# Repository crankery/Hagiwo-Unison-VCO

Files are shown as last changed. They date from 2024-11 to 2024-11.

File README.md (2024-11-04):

# Hagiwo Unison VCO

> [!NOTE]
> This is a work in progress, I'm sure I made a mistake somewhere I'll post an update when I receive the first batch of boards. 

If you don't know Hagiwo, check out their [YouTube channel](https://www.youtube.com/@HAGIWO). He puts out new DIY Eurorack module designs all the time.

This is (what is currently) has latest module, the [Unison VCO](https://note.com/solder_state/n/na0ae5754fa9c). All I've done is switch to SMT devices to try to fit it all on a single 6hp PCB. All credit for the circuit design go to Hagiwo.

The PCB is 100x30mm so it should be pretty darned cheap to order from one of the fabs over in China. Higawo used a [Seeed Studio XIAO RA4M1](https://wiki.seeedstudio.com/getting_started_xiao_ra4m1/) microcontroller module on this one, which are about $5 ordered from Seeed. They're really quite neat.

I added a tiny OLED display module to show the currently selected waveform. The display module is available from all the usual places with with search terms like "0.42" 0.42 Inch White OLED Display LCD Module 72X40 Serial Screen White Color I2C IIC/SPI Interface SSD1306". I'm sure there's an original manufacturer of these things but I can't figure it out. The 4 pin I2C SSD1306 version that looks like this:

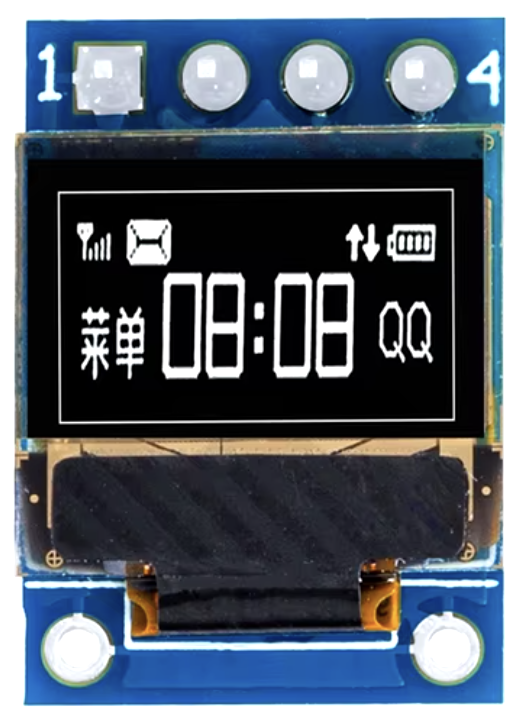
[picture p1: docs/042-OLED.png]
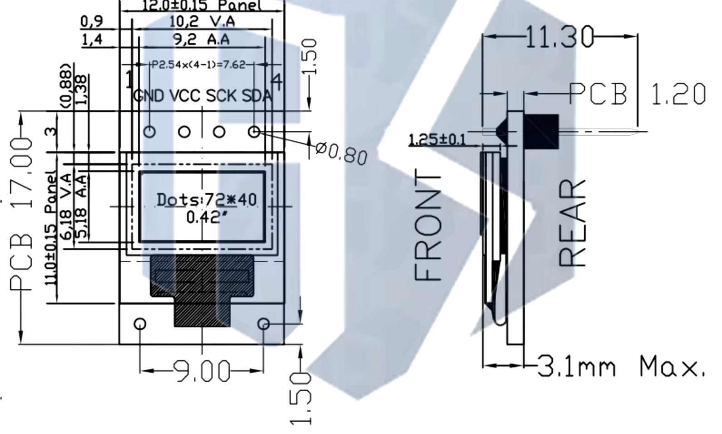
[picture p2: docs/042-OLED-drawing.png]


TODO: make incredibly insightful comments about stuff here

## Main Board

Here's some renderings of this thing. I'll take pictures of it when I actually build it.

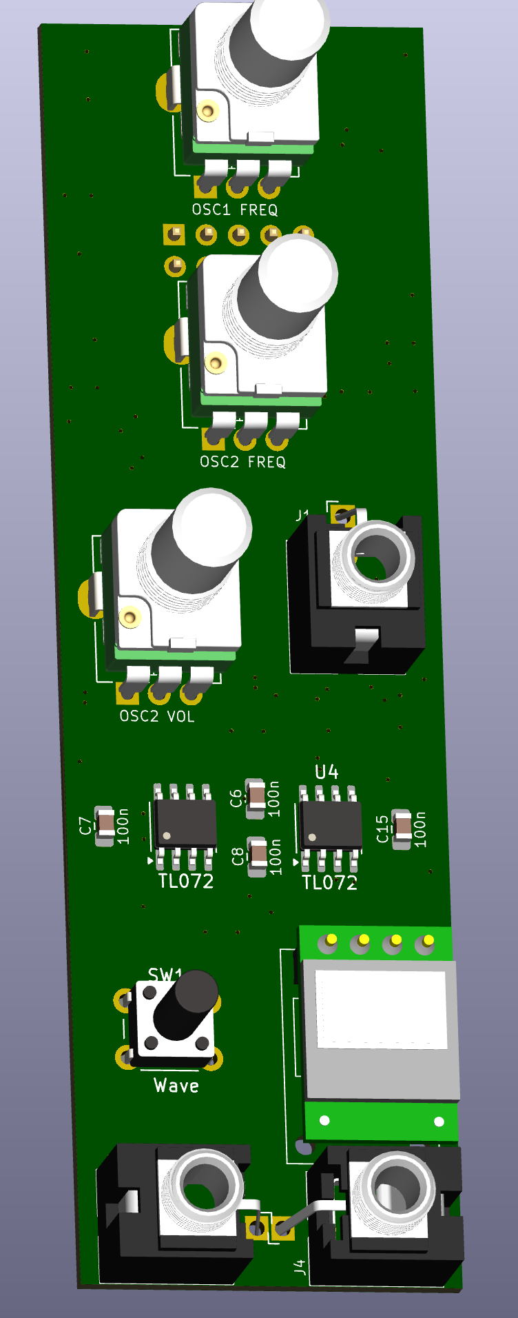
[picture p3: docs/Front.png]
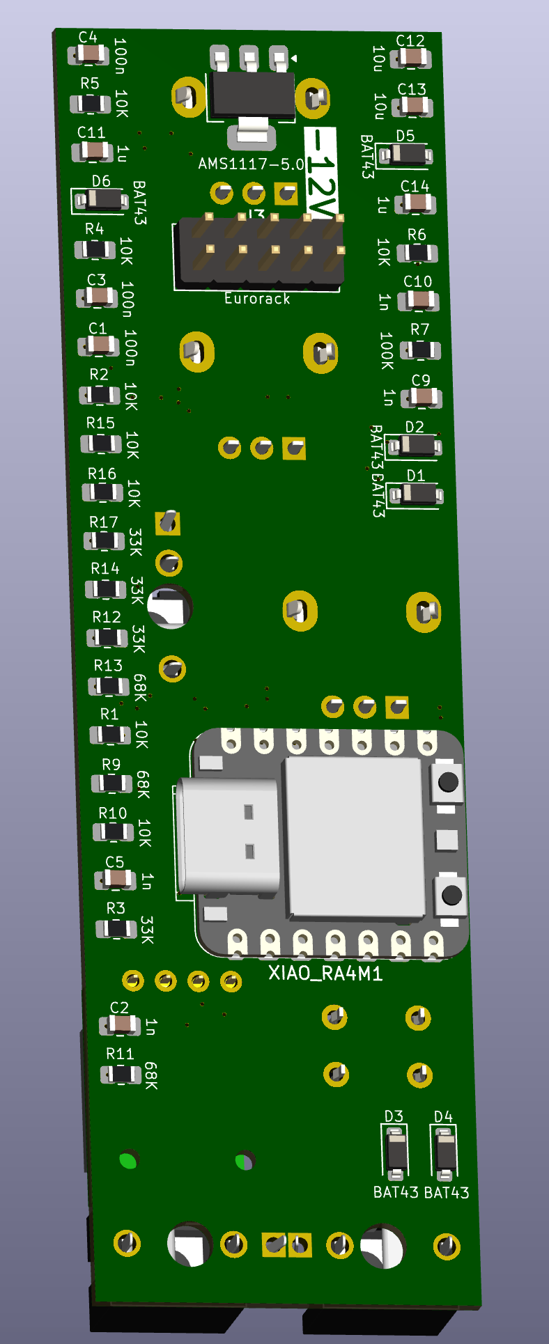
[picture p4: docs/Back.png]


## Front Panel

I created a Eurorack 6hp front panel for this in KiCad. Which is weird but hey. I don't want to pay for aluminum panels.

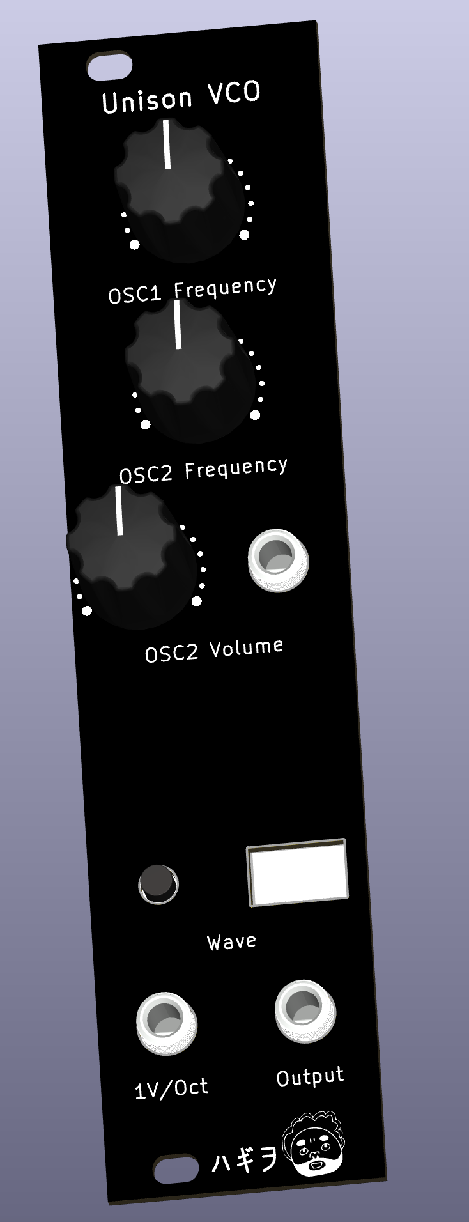
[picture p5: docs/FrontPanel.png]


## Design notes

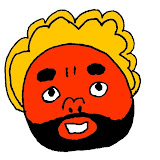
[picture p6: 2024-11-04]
FP/FP.jpg

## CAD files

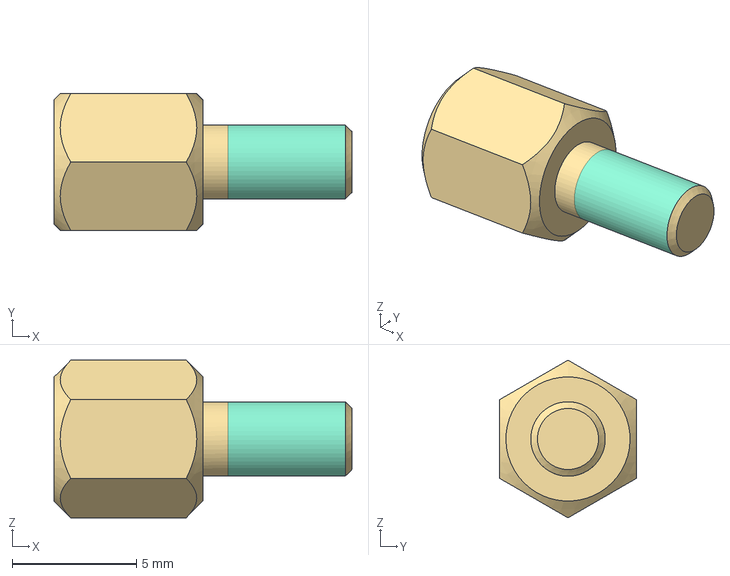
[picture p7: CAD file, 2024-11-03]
3dshapes/Abstandhalter M3 IG-AG 6mm+6mm - Messing.stp
12.0 x 5.50 x 6.35 mm

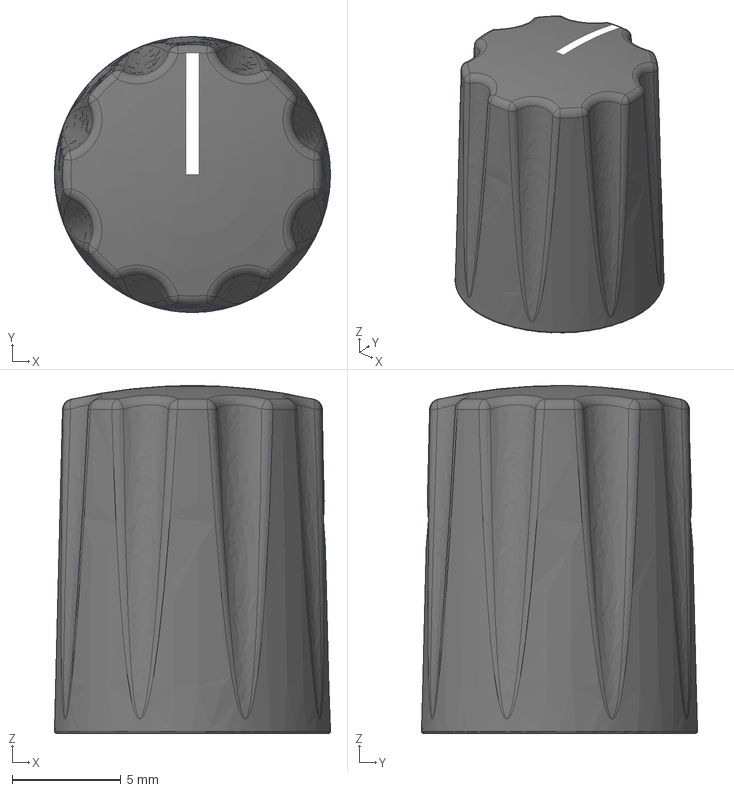
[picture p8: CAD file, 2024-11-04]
FP/3d/1900h-bk-T-D.stp
12.7 x 12.7 x 16.0 mm

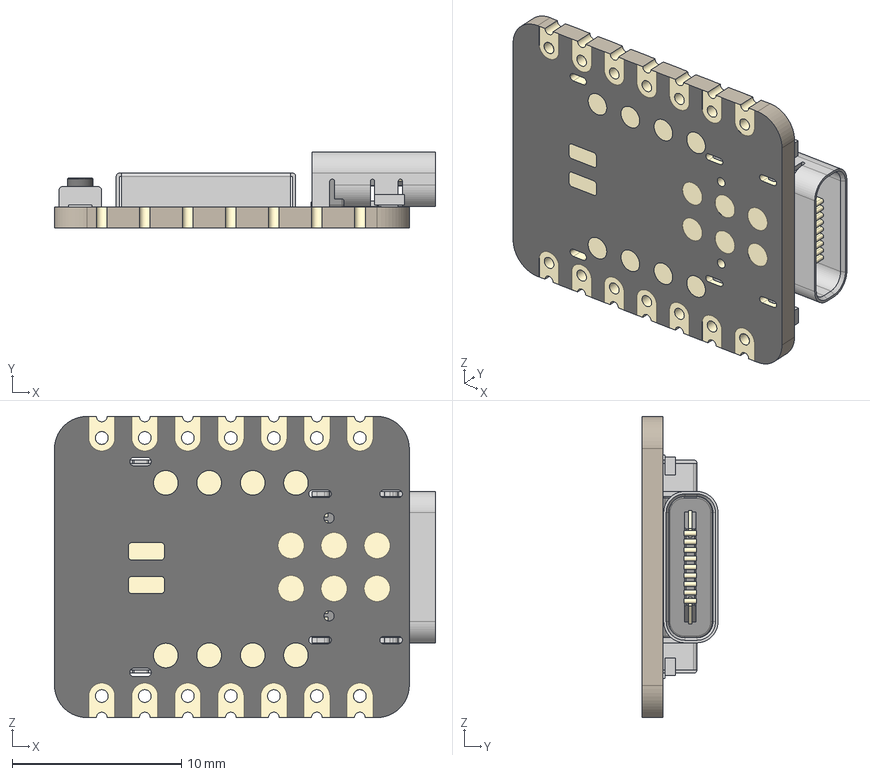
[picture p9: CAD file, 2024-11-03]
3dshapes/Seeed Studio XIAO RA4M1.step
22.5 x 4.49 x 17.8 mm
BOSS-EXTRUDE14_8_
BOSS-EXTRUDE7_4_
BOSS-EXTRUDE7_3_
BOSS-EXTRUDE14_4_
BOSS-EXTRUDE14_2_
BOSS-EXTRUDE14_11_
BOSS-EXTRUDE7_7_
BOSS-EXTRUDE14_9_
BOSS-EXTRUDE14_3_
BOSS-EXTRUDE14_7_
MIRROR2
BOSS-EXTRUDE14_5_
BOSS-EXTRUDE14_12_
BOSS-EXTRUDE7_8_
BOSS-EXTRUDE7_1_
BOSS-EXTRUDE14_10_
BOSS-EXTRUDE7_9_
BOSS-EXTRUDE14_6_
BOSS-EXTRUDE14_1_
BOSS-EXTRUDE7_6_
BOSS-EXTRUDE7_2_
CUT-EXTRUDE5
BOSS-EXTRUDE7_5_
Button (1) x 2
Shield

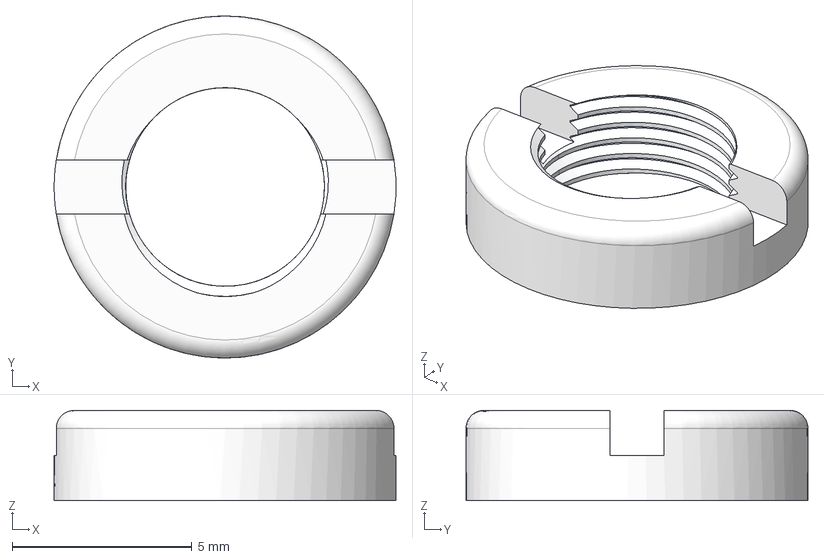
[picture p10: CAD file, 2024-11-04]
FP/3d/Bananut M6 Silver.step
9.50 x 9.51 x 2.51 mm

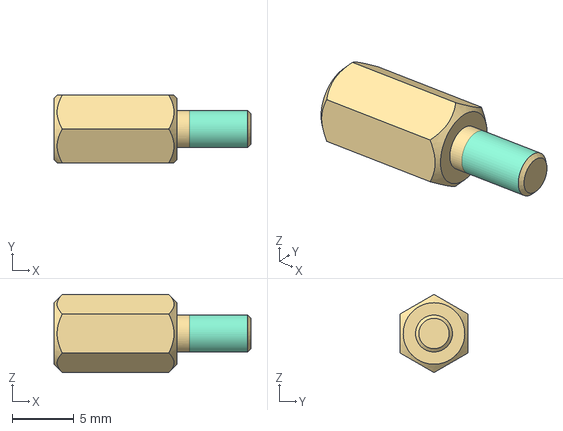
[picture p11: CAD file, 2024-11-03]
3dshapes/Abstandhalter M3 IG-AG 10mm+6mm - Messing.stp
16.0 x 5.50 x 6.35 mm

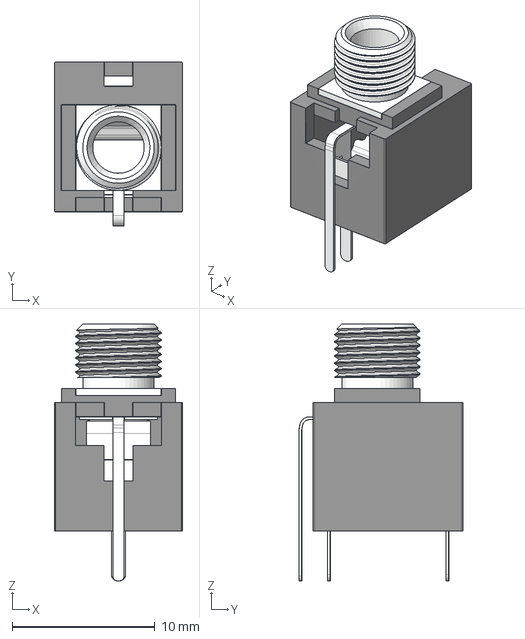
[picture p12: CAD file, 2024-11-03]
FP/3d/PJ398SM.stp
9.00 x 11.5 x 18.0 mm

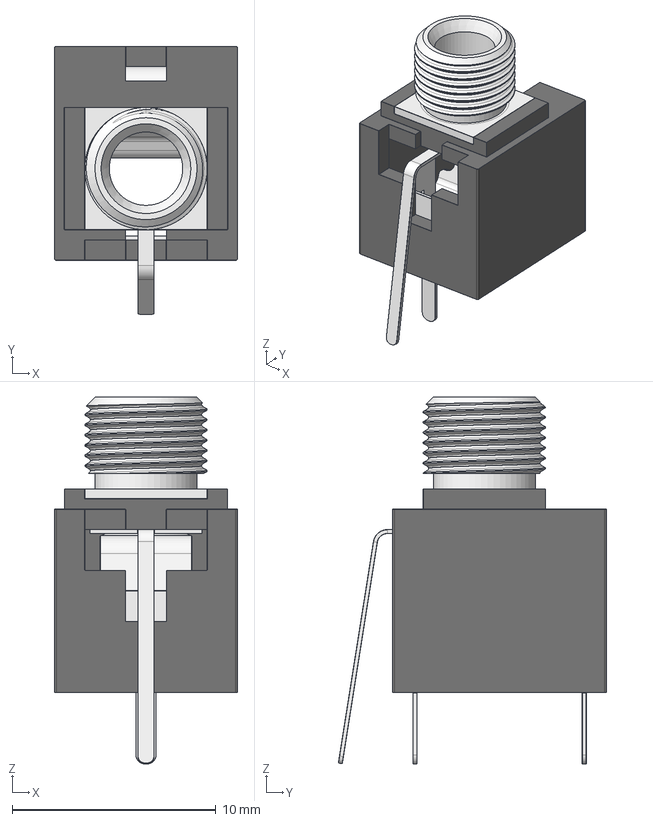
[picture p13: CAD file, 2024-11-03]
3dshapes/WQP-PJ398SM.step
9.00 x 13.2 x 18.0 mm
Pin_3
Pin_2
Pin_1
Socket

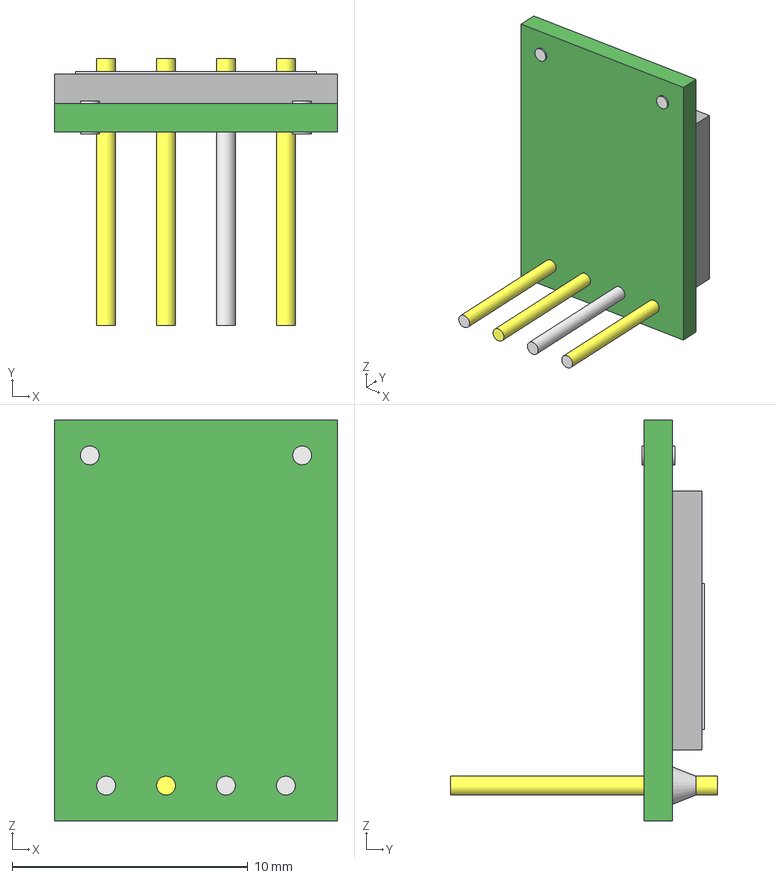
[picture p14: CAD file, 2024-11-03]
3dshapes/display.step
12.0 x 11.3 x 17.0 mm

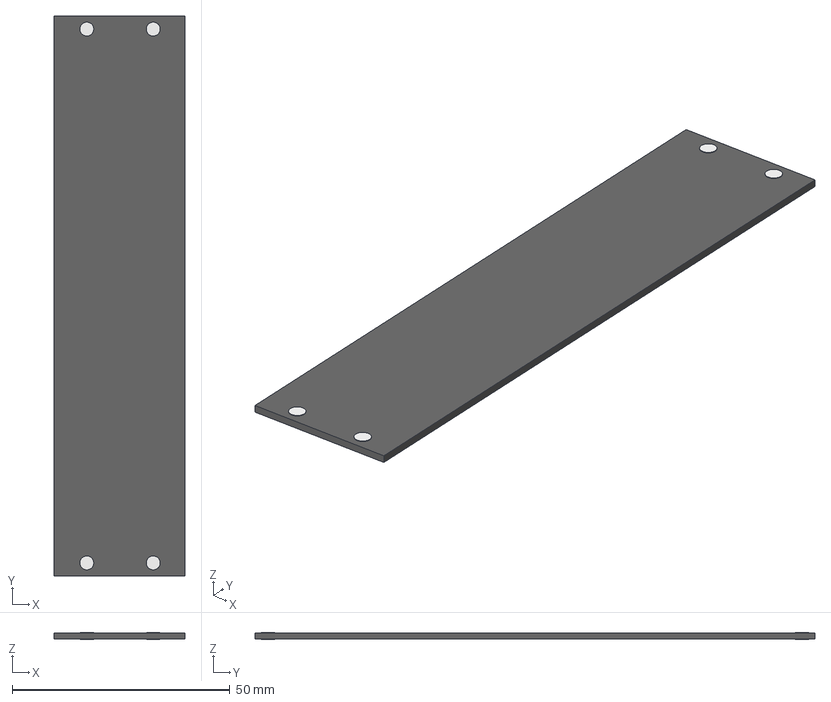
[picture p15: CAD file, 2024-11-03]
3dshapes/fp.step
30.0 x 128.5 x 1.60 mm

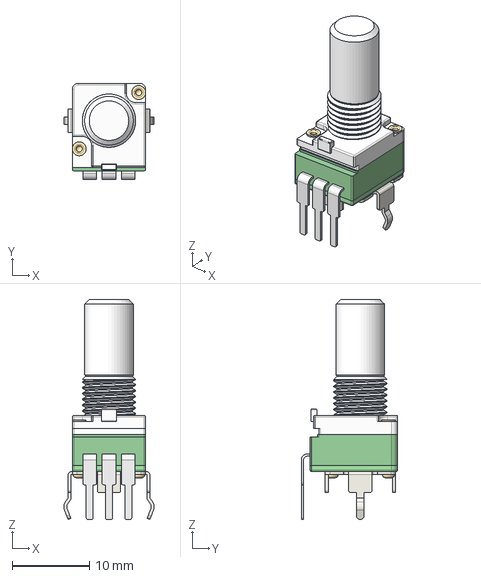
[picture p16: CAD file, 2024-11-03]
3dshapes/RD901F-40-15R1.step
11.7 x 12.5 x 28.5 mm

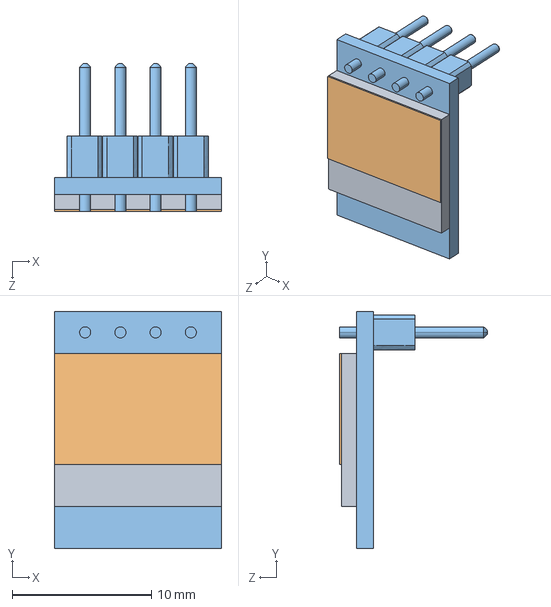
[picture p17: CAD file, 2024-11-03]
3dshapes/042oled.STEP
12.0 x 17.0 x 10.7 mm

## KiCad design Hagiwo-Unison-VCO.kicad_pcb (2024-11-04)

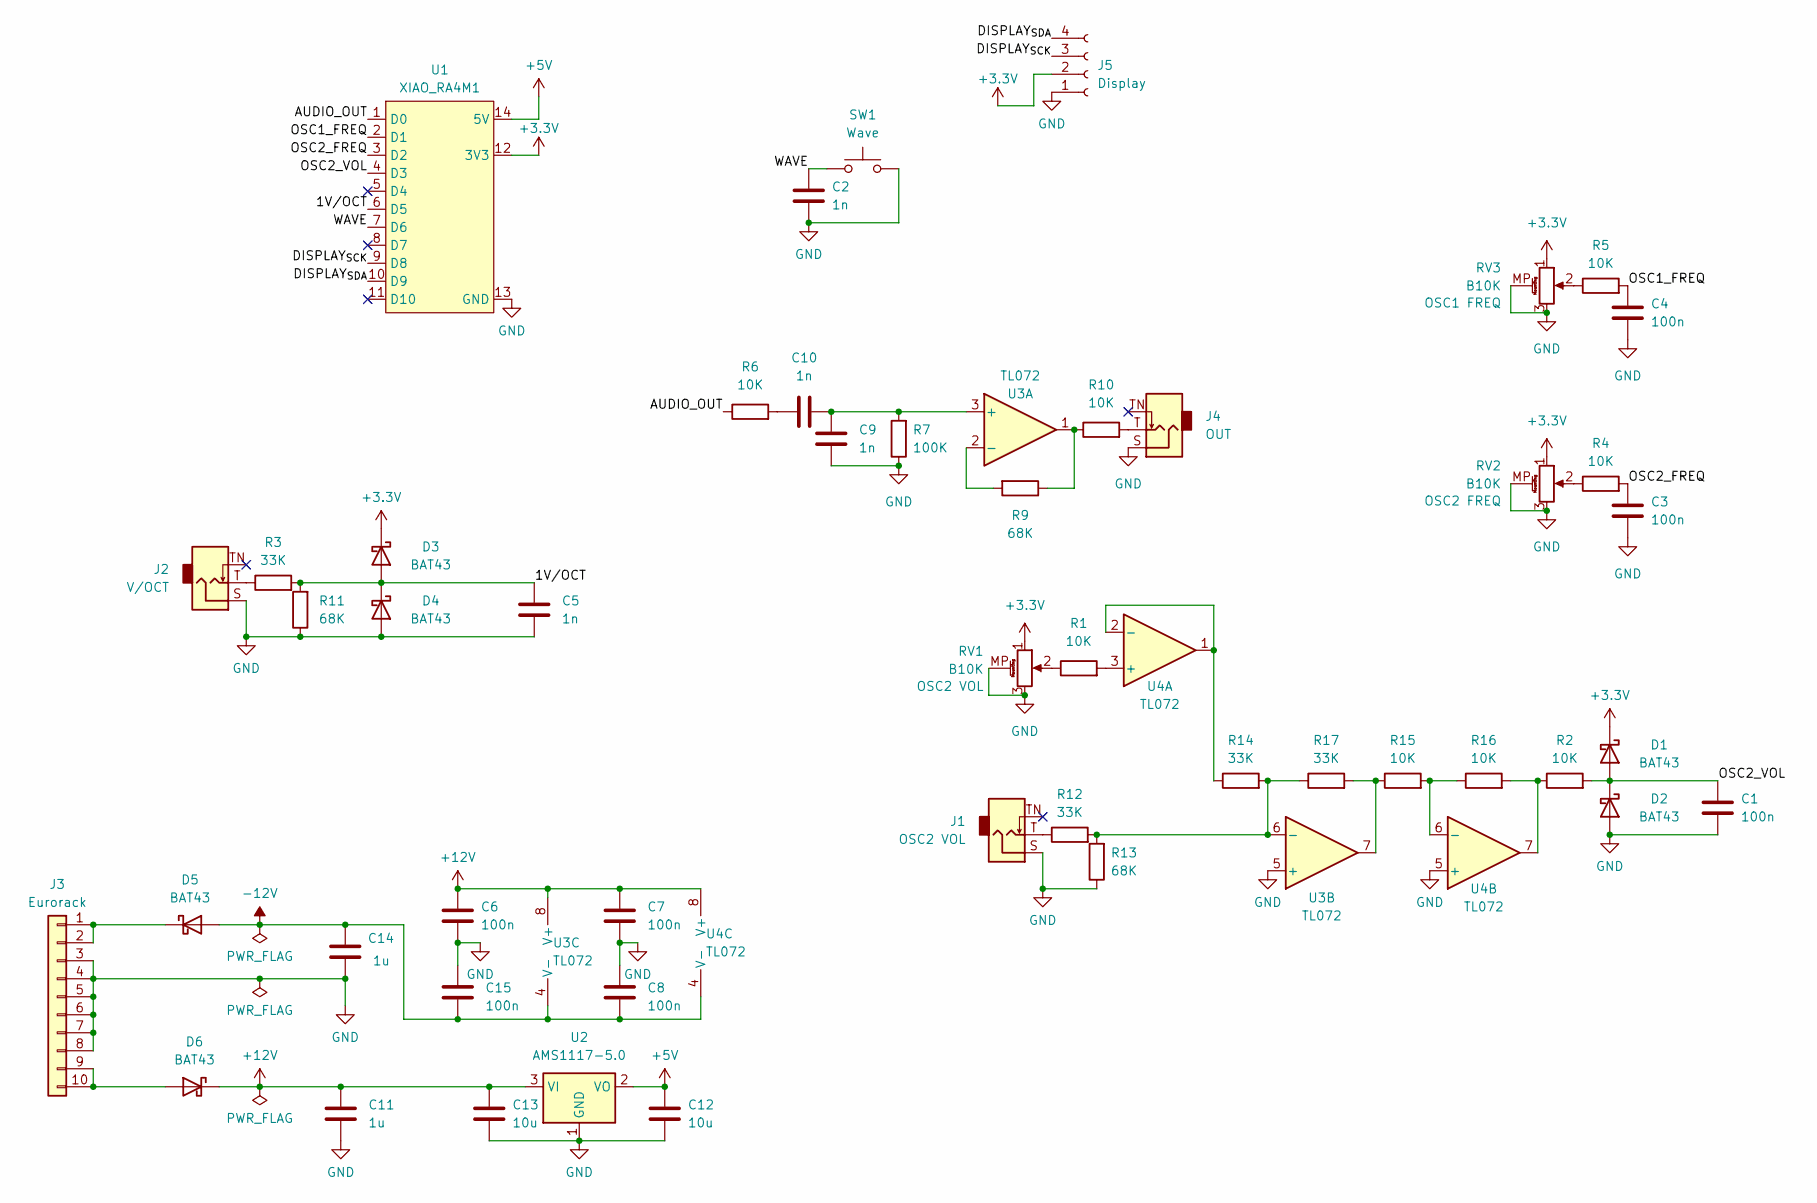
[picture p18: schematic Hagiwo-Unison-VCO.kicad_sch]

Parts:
C1, C3, C4, C6, C7, C8, C15: 100n; C_0805_2012Metric_Pad1.18x1.45mm_HandSolder
C2, C5, C9, C10: 1n; C_0805_2012Metric_Pad1.18x1.45mm_HandSolder
C11, C14: 1u; C_0805_2012Metric_Pad1.18x1.45mm_HandSolder
C12, C13: 10u; C_0805_2012Metric_Pad1.18x1.45mm_HandSolder
D1, D2, D3, D4, D5, D6: BAT43; D_SOD-123
J1: OSC2 VOL; Jack_3.5mm_QingPu_WQP-PJ398SM_Vertical_CircularHoles
J2: V/OCT; Jack_3.5mm_QingPu_WQP-PJ398SM_Vertical_CircularHoles
J3: Eurorack; PinHeader_2x05_P2.54mm_Vertical
J4: OUT; Jack_3.5mm_QingPu_WQP-PJ398SM_Vertical_CircularHoles
J5: Display; 0.42_OLED
R1, R2, R4, R5, R6, R10, R15, R16: 10K; R_0805_2012Metric_Pad1.20x1.40mm_HandSolder
R3, R12, R14, R17: 33K; R_0805_2012Metric_Pad1.20x1.40mm_HandSolder
R7: 100K; R_0805_2012Metric_Pad1.20x1.40mm_HandSolder
R9, R11, R13: 68K; R_0805_2012Metric_Pad1.20x1.40mm_HandSolder
RV1, RV2, RV3: B10K; Potentiometer_Alpha_RD901F-40-00D_Single_Vertical
SW1: Wave; SW_PUSH_6mm_H13mm
U1: XIAO_RA4M1; Seeed XIAO RA4M1 Basic
U2: AMS1117-5.0; SOT-223-3_TabPin2
U3, U4: TL072; SOIC-8_3.9x4.9mm_P1.27mm

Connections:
+3.3V: D1.1 (K), D3.1 (K), J5.2, RV1.1, RV2.1, RV3.1, U1.12 (3V3)
+5V: C12.2, U1.14 (5V), U2.2 (VO)
+12V: C6.2, C7.2, C11.2, C13.2, D6.1 (K), U2.3 (VI), U3.8 (V+), U4.8 (V+)
-12V: C8.1, C14.2, C15.1, D5.2 (A), U3.4 (V-), U4.4 (V-)
/1V/OCT: C5.2, D3.2 (A), D4.1 (K), R3.2, R11.2, U1.6 (D5)
/AUDIO_OUT: R6.1, U1.1 (D0)
/DISPLAY_{SCK}: J5.3, U1.9 (D8)
/DISPLAY_{SDA}: J5.4, U1.10 (D9)
/OSC1_FREQ: C4.2, R5.2, U1.2 (D1)
/OSC2_FREQ: C3.2, R4.2, U1.3 (D2)
/OSC2_VOL: C1.2, D1.2 (A), D2.1 (K), R2.2, U1.4 (D3)
/WAVE: C2.2, SW1.1, U1.7 (D6)
GND: C1.1, C2.1, C3.1, C4.1, C5.1, C6.1, C7.1, C8.2, C9.1, C11.1, C12.1, C13.1, C14.1, C15.2, D2.2 (A), D4.2 (A), J1.S, J2.S, J3.3, J3.4, J3.5, J3.6, J3.7, J3.8, J4.S, J5.1, R7.1, R11.1, R13.1, RV1.3, RV1.MP (MountPin), RV2.3, RV2.MP (MountPin), RV3.3, RV3.MP (MountPin), SW1.2, U1.13 (GND), U2.1 (GND), U3.5 (+), U4.5 (+)
unnamed: C10.2, R6.2
unnamed: D5.1 (K), J3.1, J3.2
unnamed: D6.2 (A), J3.9, J3.10
unnamed: J1.T, R12.1
unnamed: J2.T, R3.1
unnamed: J4.T, R10.2
unnamed: R1.1, RV1.2
unnamed: R4.1, RV2.2
unnamed: R5.1, RV3.2
unnamed: R9.1, R10.1, U3.1
unnamed: R15.1, R17.2, U3.7
unnamed: R2.1, R16.2, U4.7
unnamed: C9.2, C10.1, R7.2, U3.3 (+)
unnamed: R9.2, U3.2 (-)
unnamed: R12.2, R13.2, R14.2, R17.1, U3.6 (-)
unnamed: R1.2, U4.3 (+)
unnamed: R14.1, U4.1, U4.2 (-)
unnamed: R15.2, R16.1, U4.6 (-)

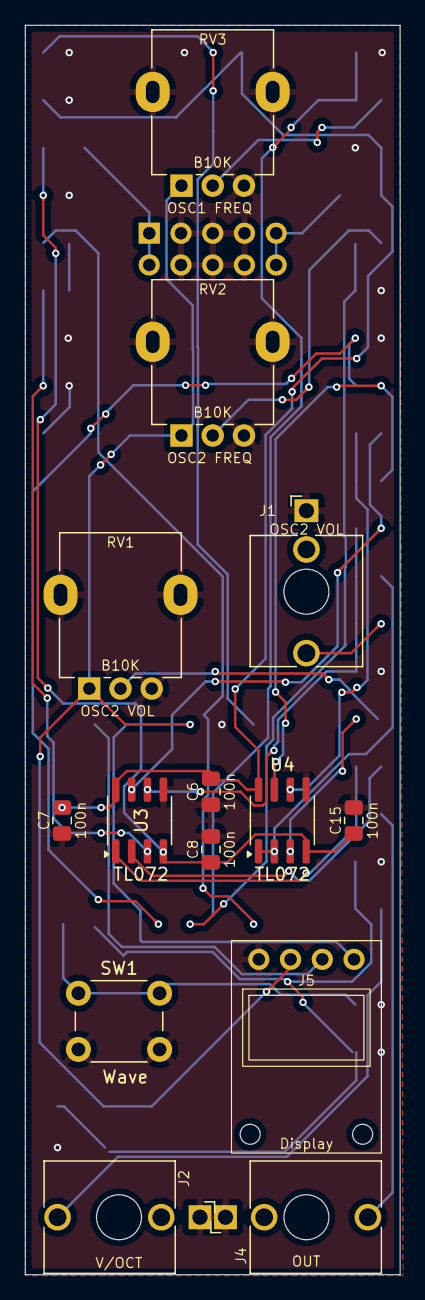
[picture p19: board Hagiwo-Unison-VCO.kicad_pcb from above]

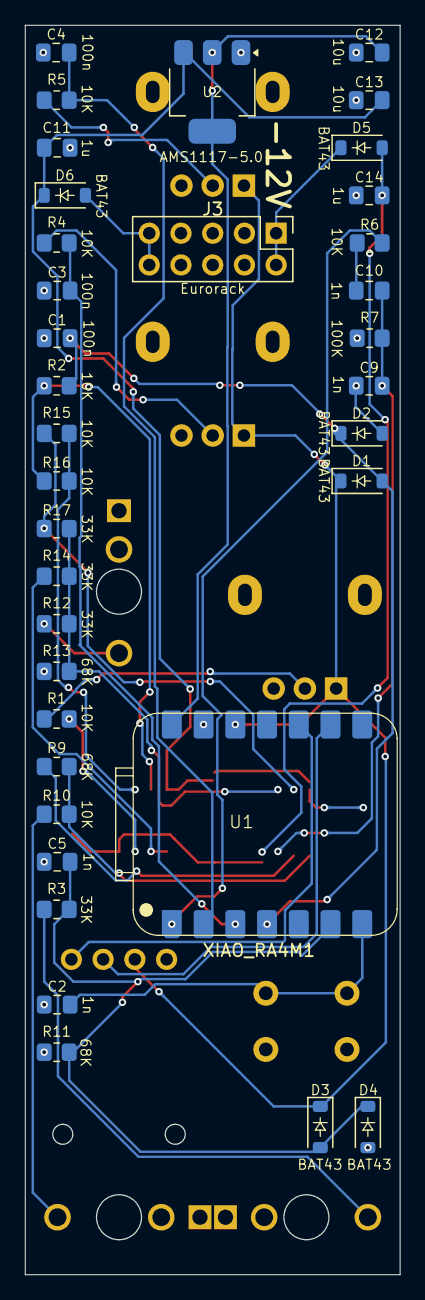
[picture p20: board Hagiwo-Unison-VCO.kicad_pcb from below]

Board: 2 copper layers, 30.0 x 100.0 mm, 50 parts (36 on the bottom side), 31 nets.

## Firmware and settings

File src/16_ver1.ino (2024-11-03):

#include <EEPROM.h>

float table_progress = 0;
float pitch = 0;
float pitch_calb = 0.985;
float table_progress2 = 0;
float pitch2 = 0;
bool wave_sw = 1;
bool old_wave_sw = 1;
int selectwave = 0;  //select waveform by ADC
int osc2vol = 0;
int octave_select = 2;
long timer = 0;
int detune_pot;
int osc_pot;
int osc_cv;
int oct_swA;
int oct_swB;
float voct_table[2048];
const int tableSize = 2048;  // table size

const static word wavetable[16][2048] = {
  //sin
  { 2047, 2053, 2060, 2066, 2072, 2078, 2085, 2091, 2097, 2104, 2110, 2116, 2122, 2129, 2135, 2141, 2147, 2154, 2160, 2166, 2173, 2179, 2185, 2191, 2198, 2204, 2210, 2216, 2223, 2229, 2235, 2241, 2248, 2254, 2260, 2266, 2273, 2279, 2285, 2291, 2298, 2304, 2310, 2316, 2323, 2329, 2335, 2341, 2347, 2354, 2360, 2366, 2372, 2378, 2385, 2391, 2397, 2403, 2409, 2416, 2422, 2428, 2434, 2440, 2446, 2453, 2459, 2465, 2471, 2477, 2483, 2489, 2496, 2502, 2508, 2514, 2520, 2526, 2532, 2538, 2545, 2551, 2557, 2563, 2569, 2575, 2581, 2587, 2593, 2599, 2605, 2611, 2617, 2623, 2629, 2635, 2641, 2647, 2653, 2659, 2665, 2671, 2677, 2683, 2689, 2695, 2701, 2707, 2713, 2719, 2725, 2731, 2737, 2743, 2749, 2754, 2760, 2766, 2772, 2778, 2784, 2790, 2796, 2801, 2807, 2813, 2819, 2825, 2831, 2836, 2842, 2848, 2854, 2859, 2865, 2871, 2877, 2882, 2888, 2894, 2900, 2905, 2911, 2917, 2922, 2928, 2934, 2939, 2945, 2951, 2956, 2962, 2968, 2973, 2979, 2984, 2990, 2996, 3001, 3007, 3012, 3018, 3023, 3029, 3034, 3040, 3045, 3051, 3056, 3062, 3067, 3073, 3078, 3083, 3089, 3094, 3100, 3105, 3110, 3116, 3121, 3126, 3132, 3137, 3142, 3148, 3153, 3158, 3164, 3169, 3174, 3179, 3185, 3190, 3195, 3200, 3205, 3211, 3216, 3221, 3226, 3231, 3236, 3241, 3246, 3252, 3257, 3262, 3267, 3272, 3277, 3282, 3287, 3292, 3297, 3302, 3307, 3312, 3317, 3321, 3326, 3331, 3336, 3341, 3346, 3351, 3356, 3360, 3365, 3370, 3375, 3380, 3384, 3389, 3394, 3399, 3403, 3408, 3413, 3417, 3422, 3427, 3431, 3436, 3441, 3445, 3450, 3454, 3459, 3463, 3468, 3472, 3477, 3481, 3486, 3490, 3495, 3499, 3504, 3508, 3512, 3517, 3521, 3526, 3530, 3534, 3539, 3543, 3547, 3551, 3556, 3560, 3564, 3568, 3573, 3577, 3581, 3585, 3589, 3593, 3597, 3601, 3606, 3610, 3614, 3618, 3622, 3626, 3630, 3634, 3638, 3642, 3646, 3649, 3653, 3657, 3661, 3665, 3669, 3673, 3676, 3680, 3684, 3688, 3692, 3695, 3699, 3703, 3706, 3710, 3714, 3717, 3721, 3725, 3728, 3732, 3735, 3739, 3742, 3746, 3749, 3753, 3756, 3760, 3763, 3767, 3770, 3773, 3777, 3780, 3784, 3787, 3790, 3793, 3797, 3800, 3803, 3806, 3810, 3813, 3816, 3819, 3822, 3825, 3829, 3832, 3835, 3838, 3841, 3844, 3847, 3850, 3853, 3856, 3859, 3862, 3864, 3867, 3870, 3873, 3876, 3879, 3881, 3884, 3887, 3890, 3893, 3895, 3898, 3901, 3903, 3906, 3909, 3911, 3914, 3916, 3919, 3921, 3924, 3926, 3929, 3931, 3934, 3936, 3939, 3941, 3943, 3946, 3948, 3950, 3953, 3955, 3957, 3960, 3962, 3964, 3966, 3968, 3971, 3973, 3975, 3977, 3979, 3981, 3983, 3985, 3987, 3989, 3991, 3993, 3995, 3997, 3999, 4001, 4003, 4005, 4006, 4008, 4010, 4012, 4013, 4015, 4017, 4019, 4020, 4022, 4024, 4025, 4027, 4028, 4030, 4032, 4033, 4035, 4036, 4038, 4039, 4041, 4042, 4043, 4045, 4046, 4047, 4049, 4050, 4051, 4053, 4054, 4055, 4056, 4058, 4059, 4060, 4061, 4062, 4063, 4064, 4065, 4066, 4067, 4068, 4069, 4070, 4071, 4072, 4073, 4074, 4075, 4076, 4077, 4078, 4078, 4079, 4080, 4081, 4081, 4082, 4083, 4083, 4084, 4085, 4085, 4086, 4086, 4087, 4087, 4088, 4088, 4089, 4089, 4090, 4090, 4091, 4091, 4091, 4092, 4092, 4092, 4093, 4093, 4093, 4093, 4094, 4094, 4094, 4094, 4094, 4094, 4094, 4094, 4094, 4094, 4095, 4094, 4094, 4094, 4094, 4094, 4094, 4094, 4094, 4094, 4094, 4093, 4093, 4093, 4093, 4092, 4092, 4092, 4091, 4091, 4091, 4090, 4090, 4089, 4089, 4088, 4088, 4087, 4087, 4086, 4086, 4085, 4085, 4084, 4083, 4083, 4082, 4081, 4081, 4080, 4079, 4078, 4078, 4077, 4076, 4075, 4074, 4073, 4072, 4071, 4070, 4069, 4068, 4067, 4066, 4065, 4064, 4063, 4062, 4061, 4060, 4059, 4058, 4056, 4055, 4054, 4053, 4051, 4050, 4049, 4047, 4046, 4045, 4043, 4042, 4041, 4039, 4038, 4036, 4035, 4033, 4032, 4030, 4028, 4027, 4025, 4024, 4022, 4020, 4019, 4017, 4015, 4013, 4012, 4010, 4008, 4006, 4005, 4003, 4001, 3999, 3997, 3995, 3993, 3991, 3989, 3987, 3985, 3983, 3981, 3979, 3977, 3975, 3973, 3971, 3968, 3966, 3964, 3962, 3960, 3957, 3955, 3953, 3950, 3948, 3946, 3943, 3941, 3939, 3936, 3934, 3931, 3929, 3926, 3924, 3921, 3919, 3916, 3914, 3911, 3909, 3906, 3903, 3901, 3898, 3895, 3893, 3890, 3887, 3884, 3881, 3879, 3876, 3873, 3870, 3867, 3864, 3862, 3859, 3856, 3853, 3850, 3847, 3844, 3841, 3838, 3835, 3832, 3829, 3825, 3822, 3819, 3816, 3813, 3810, 3806, 3803, 3800, 3797, 3793, 3790, 3787, 3784, 3780, 3777, 3773, 3770, 3767, 3763, 3760, 3756, 3753, 3749, 3746, 3742, 3739, 3735, 3732, 3728, 3725, 3721, 3717, 3714, 3710, 3706, 3703, 3699, 3695, 3692, 3688, 3684, 3680, 3676, 3673, 3669, 3665, 3661, 3657, 3653, 3649, 3646, 3642, 3638, 3634, 3630, 3626, 3622, 3618, 3614, 3610, 3606, 3601, 3597, 3593, 3589, 3585, 3581, 3577, 3573, 3568, 3564, 3560, 3556, 3551, 3547, 3543, 3539, 3534, 3530, 3526, 3521, 3517, 3512, 3508, 3504, 3499, 3495, 3490, 3486, 3481, 3477, 3472, 3468, 3463, 3459, 3454, 3450, 3445, 3441, 3436, 3431, 3427, 3422, 3417, 3413, 3408, 3403, 3399, 3394, 3389, 3384, 3380, 3375, 3370, 3365, 3360, 3356, 3351, 3346, 3341, 3336, 3331, 3326, 3321, 3317, 3312, 3307, 3302, 3297, 3292, 3287, 3282, 3277, 3272, 3267, 3262, 3257, 3252, 3246, 3241, 3236, 3231, 3226, 3221, 3216, 3211, 3205, 3200, 3195, 3190, 3185, 3179, 3174, 3169, 3164, 3158, 3153, 3148, 3142, 3137, 3132, 3126, 3121, 3116, 3110, 3105, 3100, 3094, 3089, 3083, 3078, 3073, 3067, 3062, 3056, 3051, 3045, 3040, 3034, 3029, 3023, 3018, 3012, 3007, 3001, 2996, 2990, 2984, 2979, 2973, 2968, 2962, 2956, 2951, 2945, 2939, 2934, 2928, 2922, 2917, 2911, 2905, 2900, 2894, 2888, 2882, 2877, 2871, 2865, 2859, 2854, 2848, 2842, 2836, 2831, 2825, 2819, 2813, 2807, 2801, 2796, 2790, 2784, 2778, 2772, 2766, 2760, 2754, 2749, 2743, 2737, 2731, 2725, 2719, 2713, 2707, 2701, 2695, 2689, 2683, 2677, 2671, 2665, 2659, 2653, 2647, 2641, 2635, 2629, 2623, 2617, 2611, 2605, 2599, 2593, 2587, 2581, 2575, 2569, 2563, 2557, 2551, 2545, 2538, 2532, 2526, 2520, 2514, 2508, 2502, 2496, 2489, 2483, 2477, 2471, 2465, 2459, 2453, 2446, 2440, 2434, 2428, 2422, 2416, 2409, 2403, 2397, 2391, 2385, 2378, 2372, 2366, 2360, 2354, 2347, 2341, 2335, 2329, 2323, 2316, 2310, 2304, 2298, 2291, 2285, 2279, 2273, 2266, 2260, 2254, 2248, 2241, 2235, 2229, 2223, 2216, 2210, 2204, 2198, 2191, 2185, 2179, 2173, 2166, 2160, 2154, 2147, 2141, 2135, 2129, 2122, 2116, 2110, 2104, 2097, 2091, 2085, 2078, 2072, 2066, 2060, 2053, 2047, 2041, 2034, 2028, 2022, 2016, 2009, 2003, 1997, 1990, 1984, 1978, 1972, 1965, 1959, 1953, 1947, 1940, 1934, 1928, 1921, 1915, 1909, 1903, 1896, 1890, 1884, 1878, 1871, 1865, 1859, 1853, 1846, 1840, 1834, 1828, 1821, 1815, 1809, 1803, 1796, 1790, 1784, 1778, 1771, 1765, 1759, 1753, 1747, 1740, 1734, 1728, 1722, 1716, 1709, 1703, 1697, 1691, 1685, 1678, 1672, 1666, 1660, 1654, 1648, 1641, 1635, 1629, 1623, 1617, 1611, 1605, 1598, 1592, 1586, 1580, 1574, 1568, 1562, 1556, 1549, 1543, 1537, 1531, 1525, 1519, 1513, 1507, 1501, 1495, 1489, 1483, 1477, 1471, 1465, 1459, 1453, 1447, 1441, 1435, 1429, 1423, 1417, 1411, 1405, 1399, 1393, 1387, 1381, 1375, 1369, 1363, 1357, 1351, 1345, 1340, 1334, 1328, 1322, 1316, 1310, 1304, 1298, 1293, 1287, 1281, 1275, 1269, 1263, 1258, 1252, 1246, 1240, 1235, 1229, 1223, 1217, 1212, 1206, 1200, 1194, 1189, 1183, 1177, 1172, 1166, 1160, 1155, 1149, 1143, 1138, 1132, 1126, 1121, 1115, 1110, 1104, 1098, 1093, 1087, 1082, 1076, 1071, 1065, 1060, 1054, 1049, 1043, 1038, 1032, 1027, 1021, 1016, 1011, 1005, 1000, 994, 989, 984, 978, 973, 968, 962, 957, 952, 946, 941, 936, 930, 925, 920, 915, 909, 904, 899, 894, 889, 883, 878, 873, 868, 863, 858, 853, 848, 842, 837, 832, 827, 822, 817, 812, 807, 802, 797, 792, 787, 782, 777, 773, 768, 763, 758, 753, 748, 743, 738, 734, 729, 724, 719, 714, 710, 705, 700, 695, 691, 686, 681, 677, 672, 667, 663, 658, 653, 649, 644, 640, 635, 631, 626, 622, 617, 613, 608, 604, 599, 595, 590, 586, 582, 577, 573, 568, 564, 560, 555, 551, 547, 543, 538, 534, 530, 526, 521, 517, 513, 509, 505, 501, 497, 493, 488, 484, 480, 476, 472, 468, 464, 460, 456, 452, 448, 445, 441, 437, 433, 429, 425, 421, 418, 414, 410, 406, 402, 399, 395, 391, 388, 384, 380, 377, 373, 369, 366, 362, 359, 355, 352, 348, 345, 341, 338, 334, 331, 327, 324, 321, 317, 314, 310, 307, 304, 301, 297, 294, 291, 288, 284, 281, 278, 275, 272, 269, 265, 262, 259, 256, 253, 250, 247, 244, 241, 238, 235, 232, 230, 227, 224, 221, 218, 215, 213, 210, 207, 204, 201, 199, 196, 193, 191, 188, 185, 183, 180, 178, 175, 173, 170, 168, 165, 163, 160, 158, 155, 153, 151, 148, 146, 144, 141, 139, 137, 134, 132, 130, 128, 126, 123, 121, 119, 117, 115, 113, 111, 109, 107, 105, 103, 101, 99, 97, 95, 93, 91, 89, 88, 86, 84, 82, 81, 79, 77, 75, 74, 72, 70, 69, 67, 66, 64, 62, 61, 59, 58, 56, 55, 53, 52, 51, 49, 48, 47, 45, 44, 43, 41, 40, 39, 38, 36, 35, 34, 33, 32, 31, 30, 29, 28, 27, 26, 25, 24, 23, 22, 21, 20, 19, 18, 17, 16, 16, 15, 14, 13, 13, 12, 11, 11, 10, 9, 9, 8, 8, 7, 7, 6, 6, 5, 5, 4, 4, 3, 3, 3, 2, 2, 2, 1, 1, 1, 1, 0, 0, 0, 0, 0, 0, 0, 0, 0, 0, 0, 0, 0, 0, 0, 0, 0, 0, 0, 0, 0, 1, 1, 1, 1, 2, 2, 2, 3, 3, 3, 4, 4, 5, 5, 6, 6, 7, 7, 8, 8, 9, 9, 10, 11, 11, 12, 13, 13, 14, 15, 16, 16, 17, 18, 19, 20, 21, 22, 23, 24, 25, 26, 27, 28, 29, 30, 31, 32, 33, 34, 35, 36, 38, 39, 40, 41, 43, 44, 45, 47, 48, 49, 51, 52, 53, 55, 56, 58, 59, 61, 62, 64, 66, 67, 69, 70, 72, 74, 75, 77, 79, 81, 82, 84, 86, 88, 89, 91, 93, 95, 97, 99, 101, 103, 105, 107, 109, 111, 113, 115, 117, 119, 121, 123, 126, 128, 130, 132, 134, 137, 139, 141, 144, 146, 148, 151, 153, 155, 158, 160, 163, 165, 168, 170, 173, 175, 178, 180, 183, 185, 188, 191, 193, 196, 199, 201, 204, 207, 210, 213, 215, 218, 221, 224, 227, 230, 232, 235, 238, 241, 244, 247, 250, 253, 256, 259, 262, 265, 269, 272, 275, 278, 281, 284, 288, 291, 294, 297, 301, 304, 307, 310, 314, 317, 321, 324, 327, 331, 334, 338, 341, 345, 348, 352, 355, 359, 362, 366, 369, 373, 377, 380, 384, 388, 391, 395, 399, 402, 406, 410, 414, 418, 421, 425, 429, 433, 437, 441, 445, 448, 452, 456, 460, 464, 468, 472, 476, 480, 484, 488, 493, 497, 501, 505, 509, 513, 517, 521, 526, 530, 534, 538, 543, 547, 551, 555, 560, 564, 568, 573, 577, 582, 586, 590, 595, 599, 604, 608, 613, 617, 622, 626, 631, 635, 640, 644, 649, 653, 658, 663, 667, 672, 677, 681, 686, 691, 695, 700, 705, 710, 714, 719, 724, 729, 734, 738, 743, 748, 753, 758, 763, 768, 773, 777, 782, 787, 792, 797, 802, 807, 812, 817, 822, 827, 832, 837, 842, 848, 853, 858, 863, 868, 873, 878, 883, 889, 894, 899, 904, 909, 915, 920, 925, 930, 936, 941, 946, 952, 957, 962, 968, 973, 978, 984, 989, 994, 1000, 1005, 1011, 1016, 1021, 1027, 1032, 1038, 1043, 1049, 1054, 1060, 1065, 1071, 1076, 1082, 1087, 1093, 1098, 1104, 1110, 1115, 1121, 1126, 1132, 1138, 1143, 1149, 1155, 1160, 1166, 1172, 1177, 1183, 1189, 1194, 1200, 1206, 1212, 1217, 1223, 1229, 1235, 1240, 1246, 1252, 1258, 1263, 1269, 1275, 1281, 1287, 1293, 1298, 1304, 1310, 1316, 1322, 1328, 1334, 1340, 1345, 1351, 1357, 1363, 1369, 1375, 1381, 1387, 1393, 1399, 1405, 1411, 1417, 1423, 1429, 1435, 1441, 1447, 1453, 1459, 1465, 1471, 1477, 1483, 1489, 1495, 1501, 1507, 1513, 1519, 1525, 1531, 1537, 1543, 1549, 1556, 1562, 1568, 1574, 1580, 1586, 1592, 1598, 1605, 1611, 1617, 1623, 1629, 1635, 1641, 1648, 1654, 1660, 1666, 1672, 1678, 1685, 1691, 1697, 1703, 1709, 1716, 1722, 1728, 1734, 1740, 1747, 1753, 1759, 1765, 1771, 1778, 1784, 1790, 1796, 1803, 1809, 1815, 1821, 1828, 1834, 1840, 1846, 1853, 1859, 1865, 1871, 1878, 1884, 1890, 1896, 1903, 1909, 1915, 1921, 1928, 1934, 1940, 1947, 1953, 1959, 1965, 1972, 1978, 1984, 1990, 1997, 2003, 2009, 2016, 2022, 2028, 2034, 2041 },
  //saw
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
void loop() {
  if (timer + 1 <= millis()) {
    old_wave_sw = wave_sw;
    wave_sw = digitalRead(D8);
    osc_cv = analogRead(A5);
    
    pitch = voct_table[(int)(osc_cv * pitch_calb) + analogRead(A1) / 2] * octave_select * 0.5;  // pitch set
    pitch2 = pitch + pitch * analogRead(A2) * 0.003;

    osc2vol = map(analogRead(A3), 0, 1023, 0, 100);  //osc2 volume rate

    if (wave_sw == 0 && old_wave_sw != 0) {
      selectwave++;
      EEPROM.write(0, selectwave);
      if (selectwave >= 16) {
        selectwave = 0;
      }
    }

    timer = millis();
  }
}

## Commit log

2024-11-04 add a pcb front panel
    [FP.kicad_pcb, FP.kicad_sch, Hagiwo-Unison-VCO.kicad_pcb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]
2024-11-04 why not make a front panel? lol
    [1900h-bk-T-D.stp, Bananut M6 Silver.step, FP.kicad_pcb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]
